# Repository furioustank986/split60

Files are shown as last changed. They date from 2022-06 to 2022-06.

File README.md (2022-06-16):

# split60
The Split60 is Huskeyboard's first full keyboard, meaning that it uses a unique case. The cases are designed to be able to combine and look like a normal 60% keyboard, although a cable will still need to connect the two halves. It is a sandwich mount case; linear switches are recommended.

The Split60 uses the traditional ANSI 60% layout, except that the spacebar is divided into 2.25u/1.25u/2.75u segments to allow the keyboard to be split.

Eight m3x0.5 * 10mm screws will be required for assembly.

The two halves are connected by a USB C-to-C cable using an i2c connection.

The keyboard uses the ATmega32u4 chip.

The keyboard does not come with any LEDs.

The typing angle is 7 degrees.

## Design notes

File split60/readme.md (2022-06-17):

# Split60

Split60

*A short description of the keyboard/project*

* Keyboard Maintainer: [huskeyboards](https://github.com/yourusername)
* Hardware Supported: *The PCBs, controllers supported*
* Hardware Availability: *Links to where you can find this hardware*

Make example for this keyboard (after setting up your build environment):

    make Split60:default

Flashing example for this keyboard:

    make Split60:default:flash

See the [build environment setup](https://docs.qmk.fm/#/getting_started_build_tools) and the [make instructions](https://docs.qmk.fm/#/getting_started_make_guide) for more information. Brand new to QMK? Start with our [Complete Newbs Guide](https://docs.qmk.fm/#/newbs).

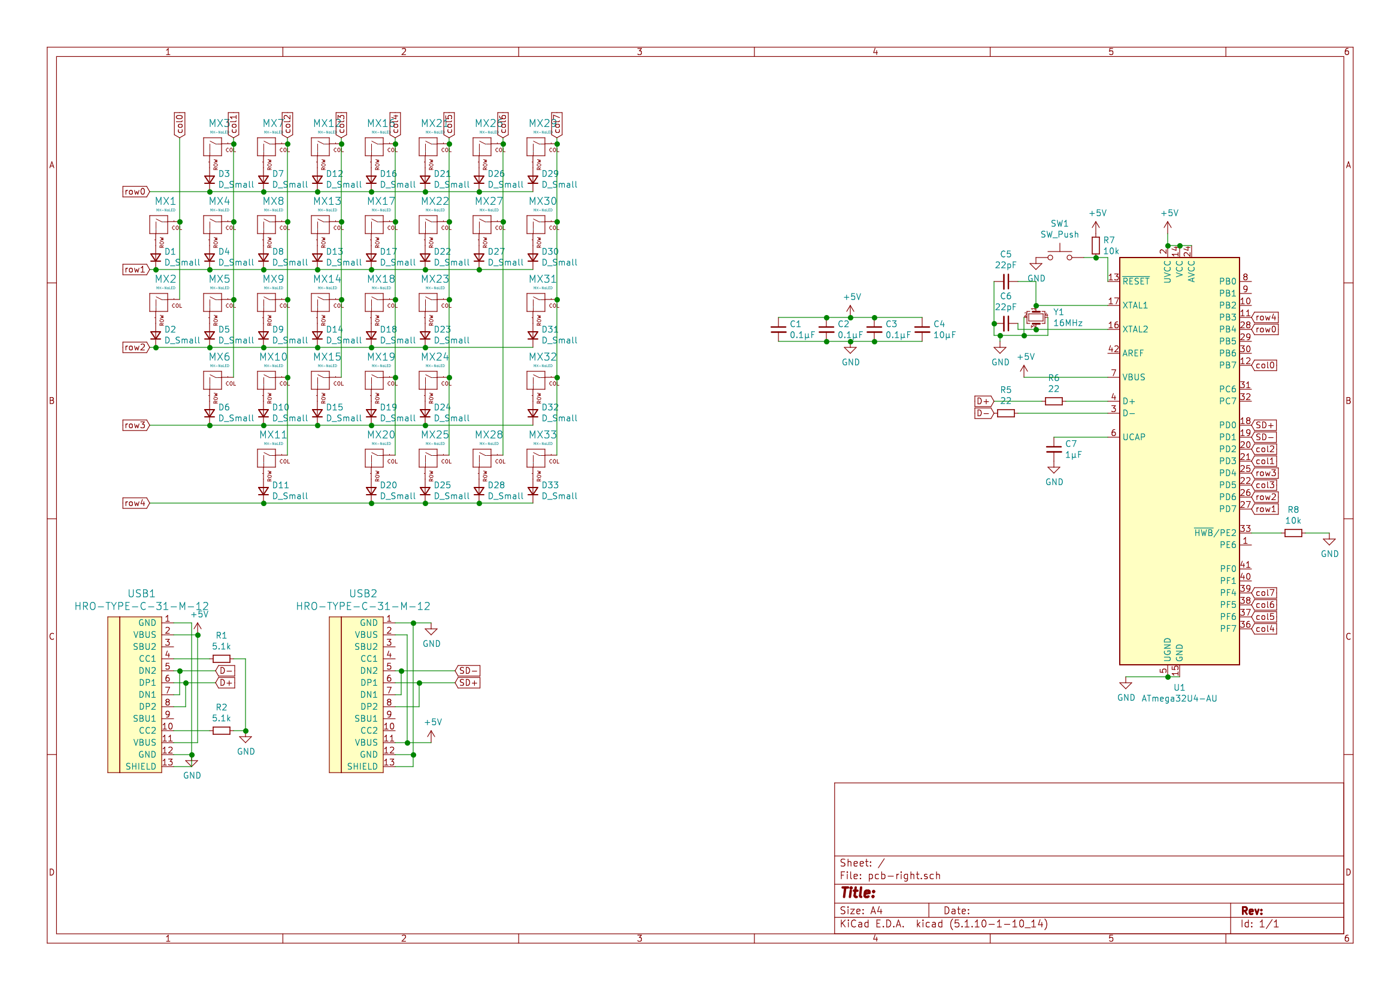
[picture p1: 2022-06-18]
pcb-right/Schematic_right.png

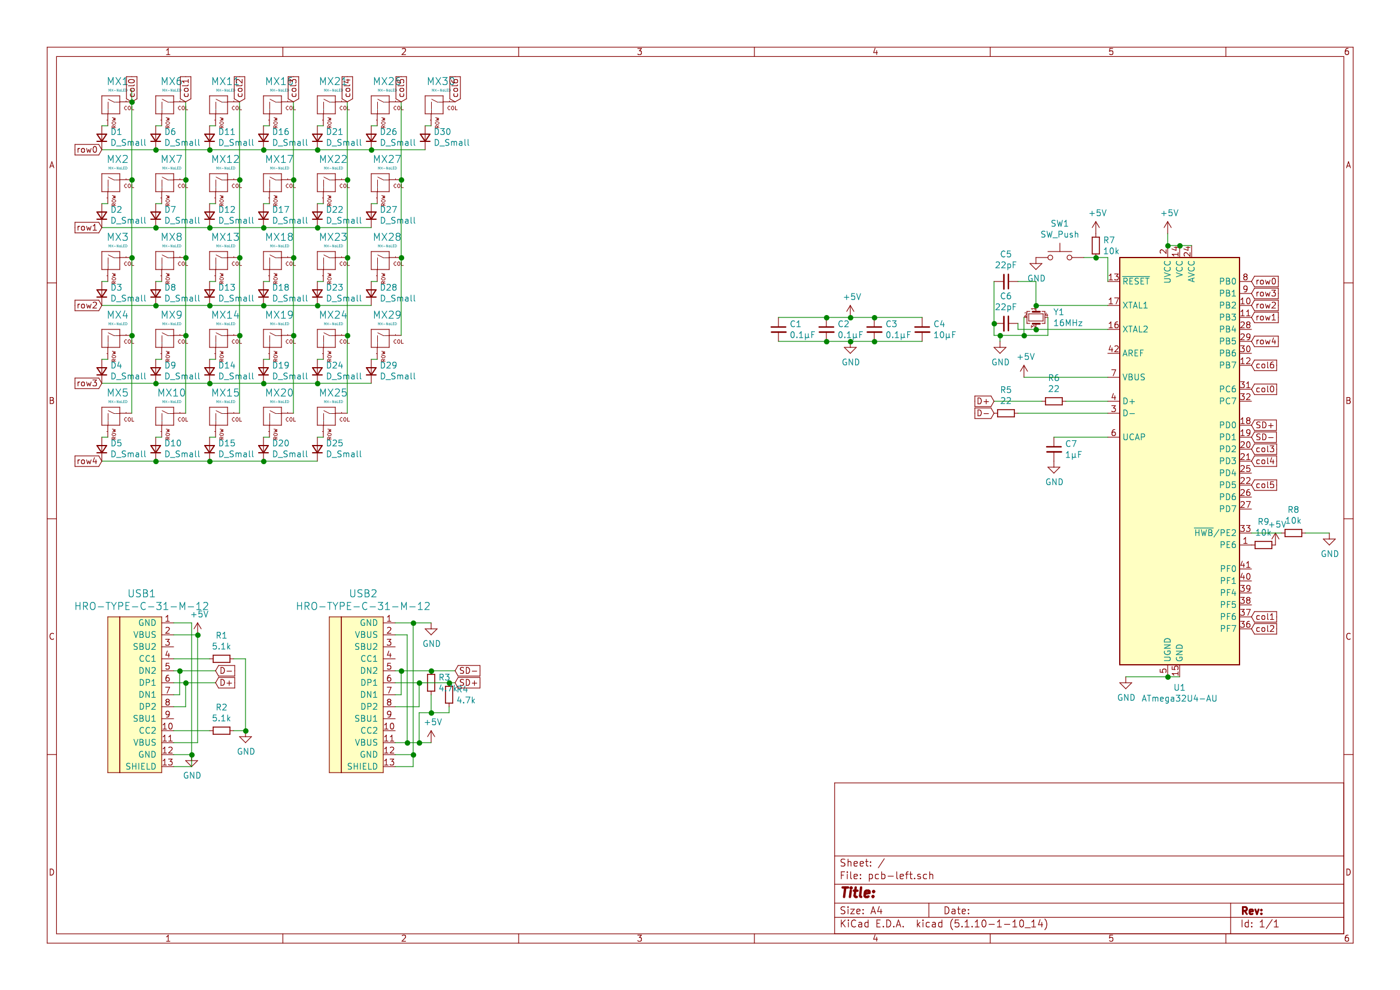
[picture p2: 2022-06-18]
pcb-left/Schematic_left.png

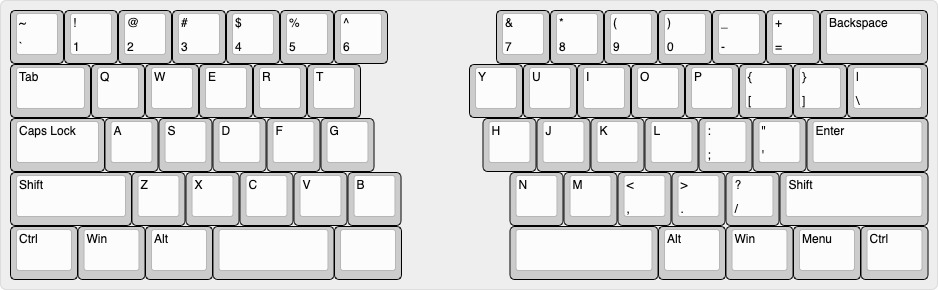
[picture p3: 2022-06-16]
keyboard-layout.jpg

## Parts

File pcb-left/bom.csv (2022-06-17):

Id | Designator | Package | Quantity | Designation | Supplier and ref
1 | MX19,MX28,MX27,MX30,MX21,MX29,MX26,MX24,MX23,MX22,MX18,MX17,MX16,MX14,MX13,MX12,MX11,MX9,MX8,MX7,MX6,MX1 | MXOnly-1U-NoLED | 22 | MX-NoLED
2 | R9,R8,R7 | R_0805_2012Metric | 3 | 10k
3 | MX20,MX4 | MXOnly-2.25U-NoLED | 2 | MX-NoLED
4 | MX15,MX25,MX10,MX5 | MXOnly-1.25U-NoLED | 4 | MX-NoLED
5 | Y1 | Crystal_SMD_3225-4Pin_3.2x2.5mm | 1 | 16MHz
6 | USB2,USB1 | HRO-TYPE-C-31-M-12-Assembly | 2 | HRO-TYPE-C-31-M-12
7 | U1 | TQFP-44_10x10mm_P0.8mm | 1 | ATmega32U4-AU
8 | SW1 | SKQG-1155865 | 1 | SW_Push
9 | R6,R5 | R_0805_2012Metric | 2 | 22
10 | R4,R3 | R_0805_2012Metric | 2 | 4.7k
11 | R2,R1 | R_0805_2012Metric | 2 | 5.1k
12 | MX3 | MXOnly-1.75U-NoLED | 1 | MX-NoLED
13 | MX2 | MXOnly-1.5U-NoLED | 1 | MX-NoLED
14 | D30,D29,D28,D27,D26,D25,D24,D23,D22,D21,D20,D19,D18,D17,D16,D15,D14,D13,D12,D11,D10,D9,D8,D7,D6,D5,D4,D3,D2,D1 | D_SOD-123 | 30 | D_Small
15 | C7 | C_0805_2012Metric | 1 | 1µF
16 | C6,C5 | C_0805_2012Metric | 2 | 22pF
17 | C4 | C_0805_2012Metric | 1 | 10µF
18 | C3,C2,C1 | C_0805_2012Metric | 3 | 0.1µF

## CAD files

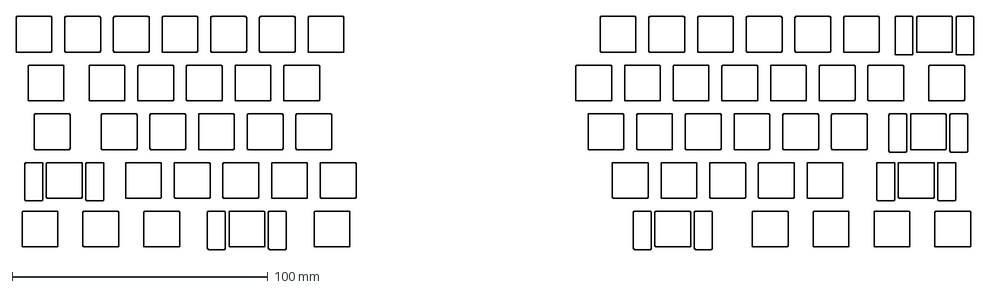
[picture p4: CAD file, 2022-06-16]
kbplate.dxf
374.9 x 91.2 mm

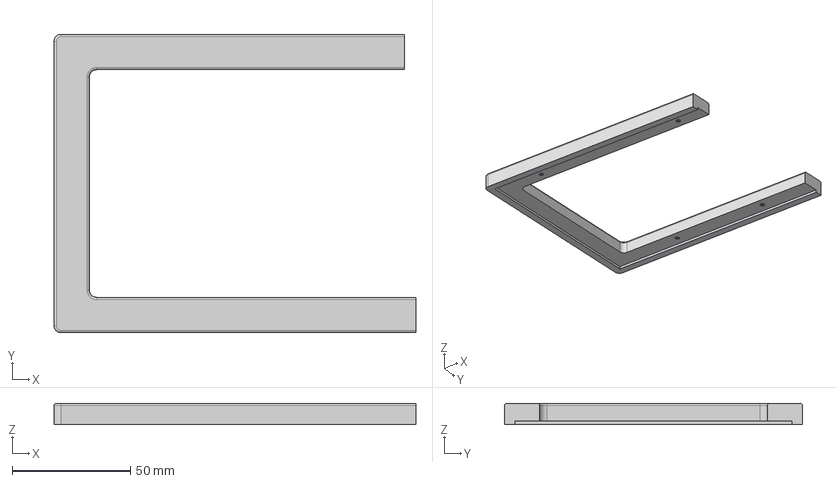
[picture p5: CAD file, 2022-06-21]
step files v2/Top-left.step
153.1 x 126.2 x 9.00 mm

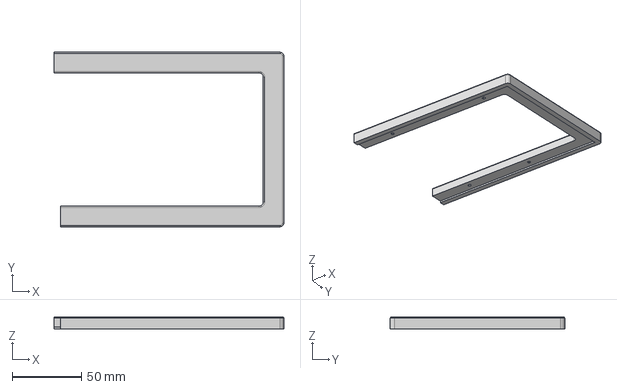
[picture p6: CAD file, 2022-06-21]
step files v2/Top-right.step
166.3 x 126.2 x 9.00 mm

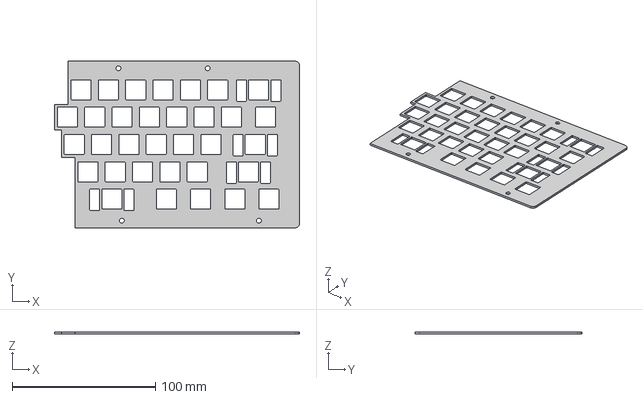
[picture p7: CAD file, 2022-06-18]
step files v2/Plate-right.step
170.8 x 116.2 x 1.50 mm

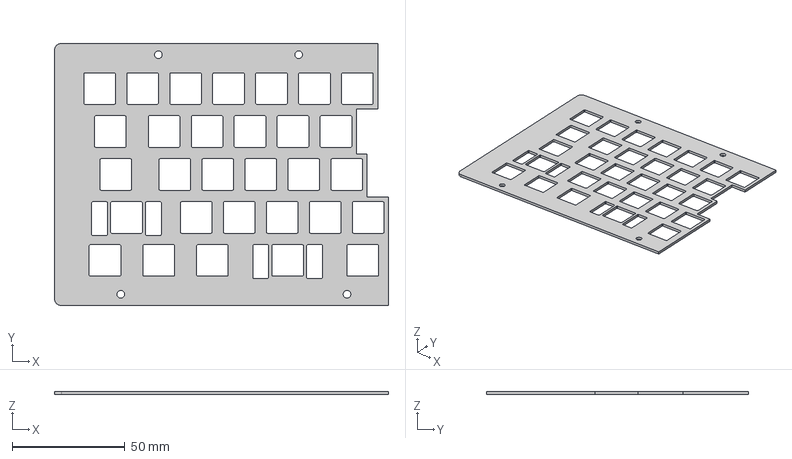
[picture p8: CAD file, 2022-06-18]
step files v2/Plate-left.step
148.1 x 116.2 x 1.50 mm

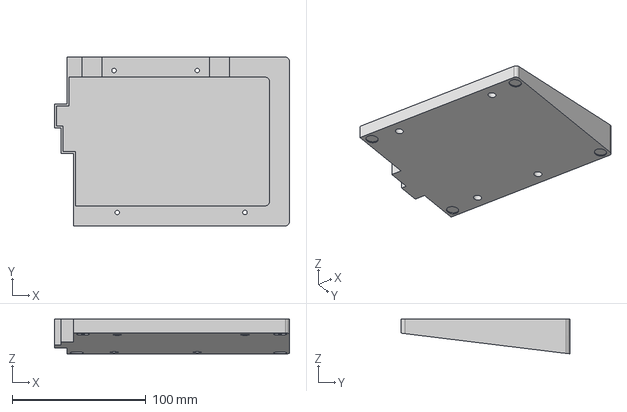
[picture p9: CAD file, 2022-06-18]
step files v2/Bottom-right.step
175.8 x 126.2 x 26.0 mm

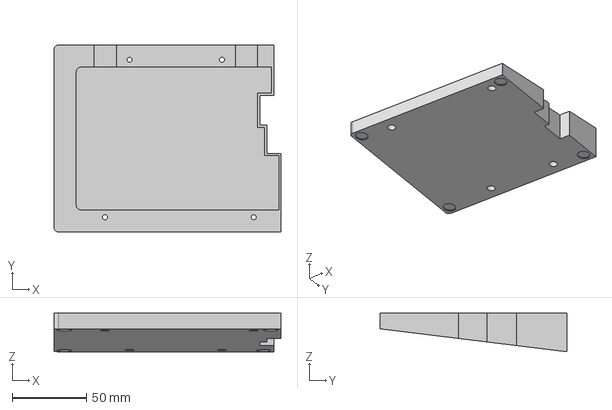
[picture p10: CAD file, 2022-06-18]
step files v2/Bottom-left.step
153.1 x 126.2 x 26.0 mm

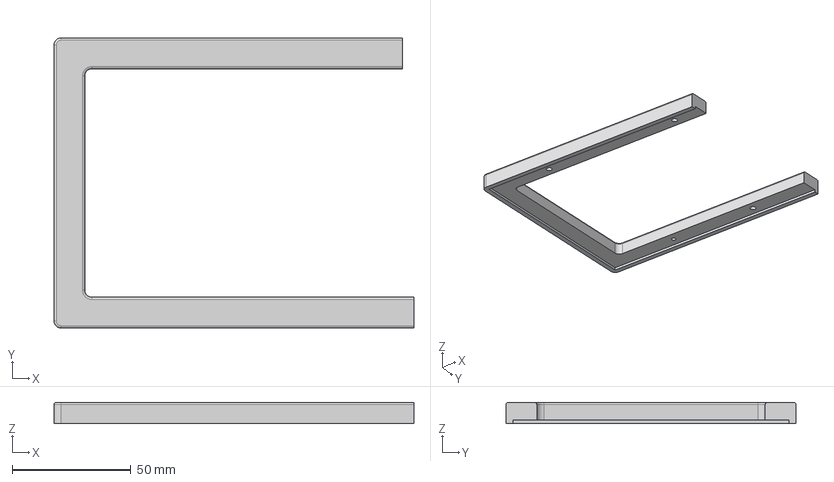
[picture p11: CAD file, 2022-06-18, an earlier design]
step files/split60_Top-left v1.step
151.6 x 122.2 x 9.00 mm

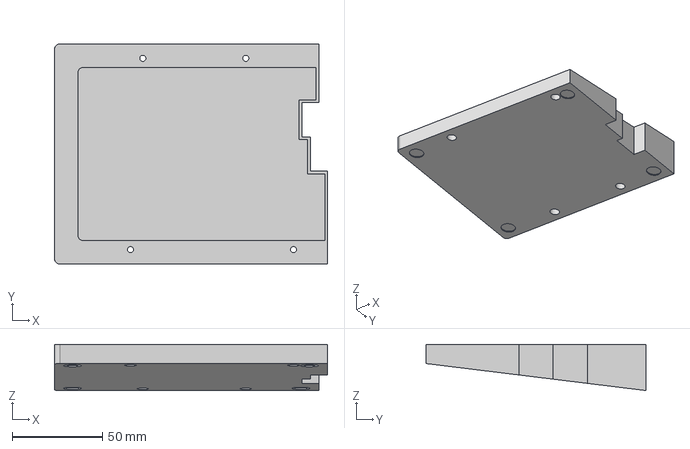
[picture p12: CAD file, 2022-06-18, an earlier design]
step files/split60_Bottom-left v1.step
151.6 x 122.2 x 25.6 mm

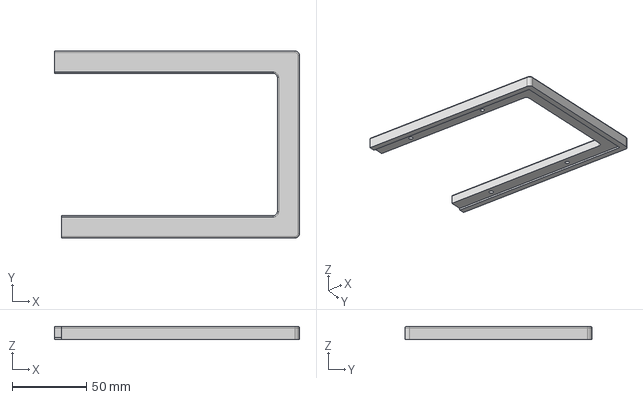
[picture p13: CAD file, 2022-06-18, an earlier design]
step files/split60_Top-right v1.step
165.5 x 126.2 x 9.00 mm

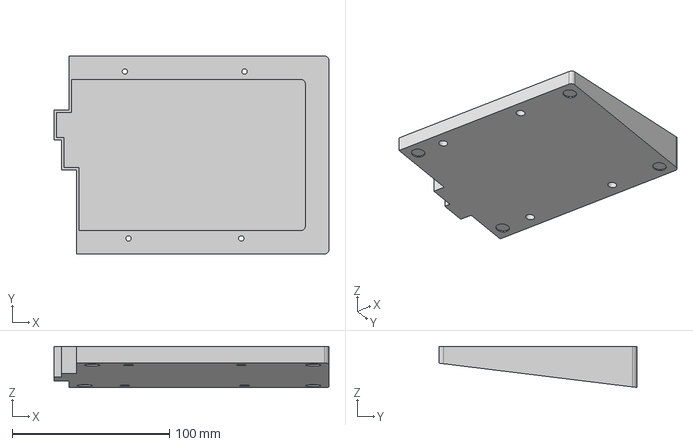
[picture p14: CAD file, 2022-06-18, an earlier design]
step files/split60_Bottom-right v1.step
175.0 x 126.2 x 26.1 mm

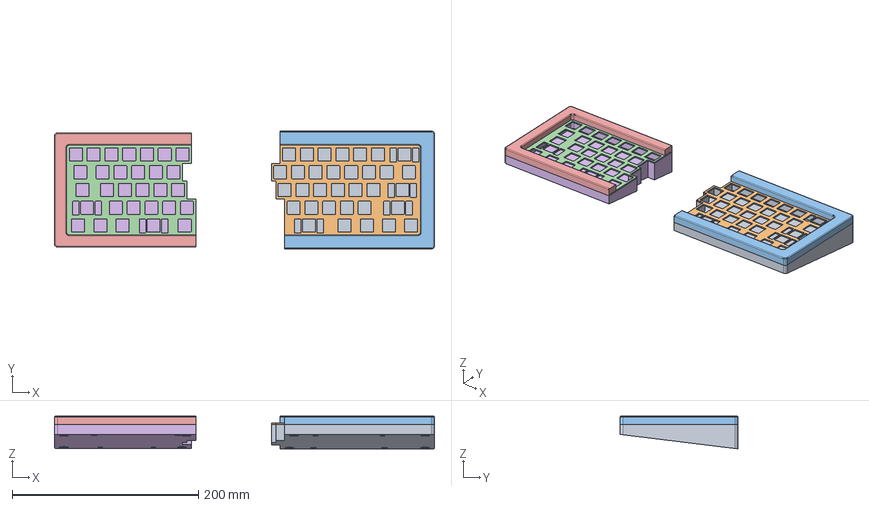
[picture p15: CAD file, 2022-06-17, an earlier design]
step files/Split60.step
407.6 x 126.2 x 35.1 mm
Bottom-right
Plate-right
Top-right
Plate-left
Top-left
Bottom-left

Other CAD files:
step files/split60_Plate-right v1.step
step files/split60_Plate-left v1.step
Split60 v2.2 _commodore_.f3d
split60 v1.f3d
split60 v2.1.f3d
split60 v2.f3d

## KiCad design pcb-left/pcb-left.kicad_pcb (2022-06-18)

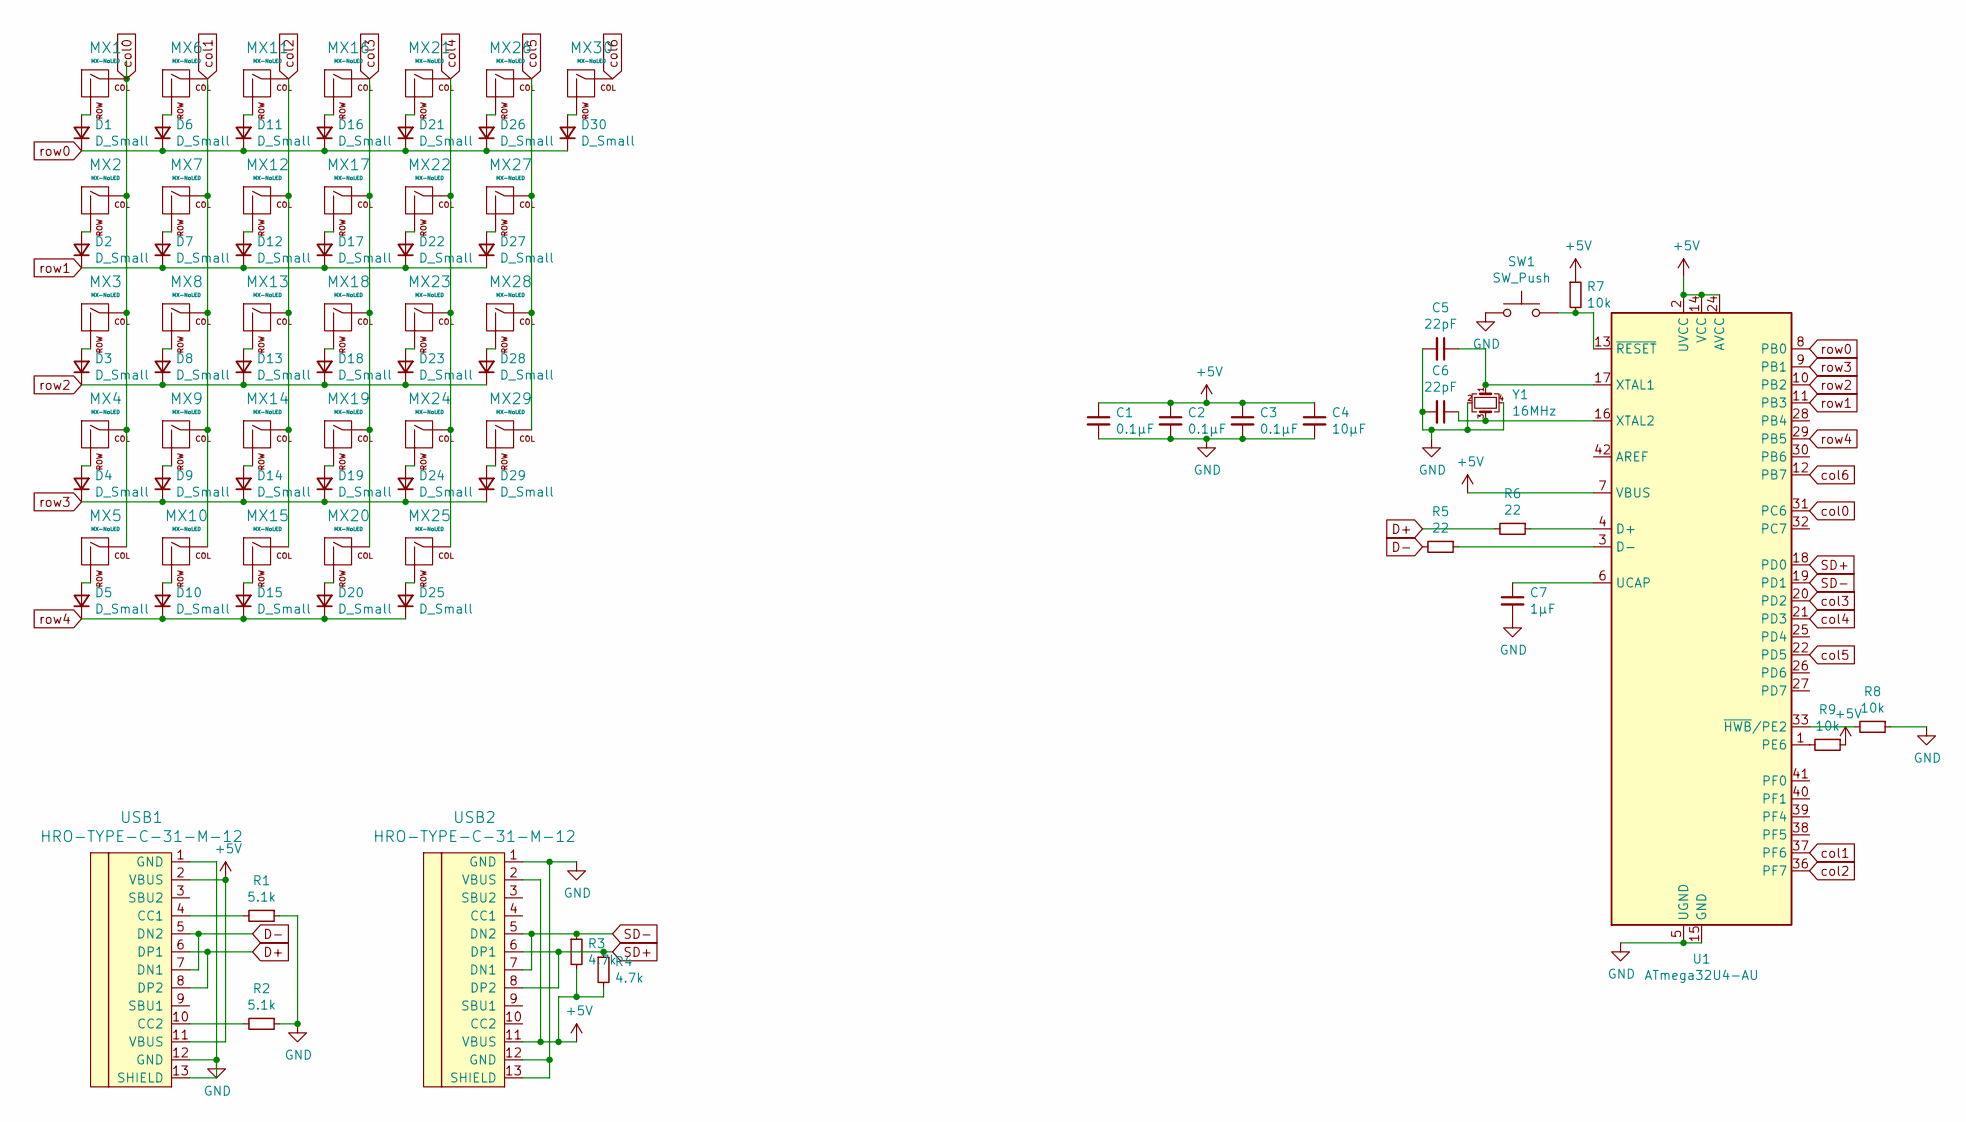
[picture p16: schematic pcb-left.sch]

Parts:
C1, C2, C3: 0.1µF; C_0805_2012Metric
C4: 10µF; C_0805_2012Metric
C5, C6: 22pF; C_0805_2012Metric
C7: 1µF; C_0805_2012Metric
D1, D2, D3, D4, D5, D6, D7, D8, D9, D10, D11, D12, D13, D14, D15, D16, D17, D18, D19, D20, D21, D22, D23, D24, D25, D26, D27, D28, D29, D30: D_Small; D_SOD-123
MX1, MX6, MX7, MX8, MX9, MX11, MX12, MX13, MX14, MX16, MX17, MX18, MX19, MX21, MX22, MX23, MX24, MX26, MX27, MX28, MX29, MX30: MX-NoLED; MXOnly-1U-NoLED
MX2: MX-NoLED; MXOnly-1.5U-NoLED
MX3: MX-NoLED; MXOnly-1.75U-NoLED
MX4, MX20: MX-NoLED; MXOnly-2.25U-NoLED
MX5, MX10, MX15, MX25: MX-NoLED; MXOnly-1.25U-NoLED
R1, R2: 5.1k; R_0805_2012Metric
R3, R4: 4.7k; R_0805_2012Metric
R5, R6: 22; R_0805_2012Metric
R7, R8, R9: 10k; R_0805_2012Metric
SW1: SW_Push; SKQG-1155865
U1: ATmega32U4-AU; TQFP-44_10x10mm_P0.8mm
USB1, USB2: HRO-TYPE-C-31-M-12; HRO-TYPE-C-31-M-12-Assembly
Y1: 16MHz; Crystal_SMD_3225-4Pin_3.2x2.5mm

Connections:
+5V: C1.1, C2.1, C3.1, C4.1, R3.2, R4.2, R7.1, R9.1, U1.2 (UVCC), U1.7 (VBUS), U1.14 (VCC), U1.24 (AVCC), U1.34 (VCC), U1.44 (AVCC), USB1.2 (VBUS), USB1.11 (VBUS), USB2.2 (VBUS), USB2.11 (VBUS)
D+: R6.2, USB1.6 (DP1), USB1.8 (DP2)
D-: R5.2, USB1.5 (DN2), USB1.7 (DN1)
GND: C1.2, C2.2, C3.2, C4.2, C5.2, C6.2, C7.2, R1.1, R2.1, R8.1, SW1.1, U1.5 (UGND), U1.15 (GND), U1.23 (GND), U1.35 (GND), U1.43 (GND), USB1.1 (GND), USB1.12 (GND), USB1.13 (SHIELD), USB2.1 (GND), USB2.12 (GND), USB2.13 (SHIELD), Y1.2, Y1.4
unnamed: C5.1, U1.17 (XTAL1), Y1.1
unnamed: C6.1, U1.16 (XTAL2), Y1.3
unnamed: C7.1, U1.6 (UCAP)
unnamed: D1.2 (A), MX1.2 (ROW)
unnamed: D2.2 (A), MX2.2 (ROW)
unnamed: D3.2 (A), MX3.2 (ROW)
unnamed: D4.2 (A), MX4.2 (ROW)
unnamed: D5.2 (A), MX5.2 (ROW)
unnamed: D6.2 (A), MX6.2 (ROW)
unnamed: D7.2 (A), MX7.2 (ROW)
unnamed: D8.2 (A), MX8.2 (ROW)
unnamed: D9.2 (A), MX9.2 (ROW)
unnamed: D10.2 (A), MX10.2 (ROW)
unnamed: D11.2 (A), MX11.2 (ROW)
unnamed: D12.2 (A), MX12.2 (ROW)
unnamed: D13.2 (A), MX13.2 (ROW)
unnamed: D14.2 (A), MX14.2 (ROW)
unnamed: D15.2 (A), MX15.2 (ROW)
unnamed: D16.2 (A), MX16.2 (ROW)
unnamed: D17.2 (A), MX17.2 (ROW)
unnamed: D18.2 (A), MX18.2 (ROW)
unnamed: D19.2 (A), MX19.2 (ROW)
unnamed: D20.2 (A), MX20.2 (ROW)
unnamed: D21.2 (A), MX21.2 (ROW)
unnamed: D22.2 (A), MX22.2 (ROW)
unnamed: D23.2 (A), MX23.2 (ROW)
unnamed: D24.2 (A), MX24.2 (ROW)
unnamed: D25.2 (A), MX25.2 (ROW)
unnamed: D26.2 (A), MX26.2 (ROW)
unnamed: D27.2 (A), MX27.2 (ROW)
unnamed: D28.2 (A), MX28.2 (ROW)
unnamed: D29.2 (A), MX29.2 (ROW)
unnamed: D30.2 (A), MX30.2 (ROW)
unnamed: R1.2, USB1.4 (CC1)
unnamed: R2.2, USB1.10 (CC2)
unnamed: R5.1, U1.3 (D-)
unnamed: R6.1, U1.4 (D+)
unnamed: R7.2, SW1.2, U1.13 (~RESET)
unnamed: R8.2, U1.33 (~HWB~/PE2)
unnamed: R9.2, U1.1 (PE6)
SD+: R4.1, U1.18 (PD0), USB2.6 (DP1), USB2.8 (DP2)
SD-: R3.1, U1.19 (PD1), USB2.5 (DN2), USB2.7 (DN1)
col0: MX1.1 (COL), MX2.1 (COL), MX3.1 (COL), MX4.1 (COL), MX5.1 (COL), U1.31 (PC6)
col1: MX6.1 (COL), MX7.1 (COL), MX8.1 (COL), MX9.1 (COL), MX10.1 (COL), U1.37 (PF6)
col2: MX11.1 (COL), MX12.1 (COL), MX13.1 (COL), MX14.1 (COL), MX15.1 (COL), U1.36 (PF7)
col3: MX16.1 (COL), MX17.1 (COL), MX18.1 (COL), MX19.1 (COL), MX20.1 (COL), U1.20 (PD2)
col4: MX21.1 (COL), MX22.1 (COL), MX23.1 (COL), MX24.1 (COL), MX25.1 (COL), U1.21 (PD3)
col5: MX26.1 (COL), MX27.1 (COL), MX28.1 (COL), MX29.1 (COL), U1.22 (PD5)
col6: MX30.1 (COL), U1.12 (PB7)
row0: D1.1 (K), D6.1 (K), D11.1 (K), D16.1 (K), D21.1 (K), D26.1 (K), D30.1 (K), U1.8 (PB0)
row1: D2.1 (K), D7.1 (K), D12.1 (K), D17.1 (K), D22.1 (K), D27.1 (K), U1.11 (PB3)
row2: D3.1 (K), D8.1 (K), D13.1 (K), D18.1 (K), D23.1 (K), D28.1 (K), U1.10 (PB2)
row3: D4.1 (K), D9.1 (K), D14.1 (K), D19.1 (K), D24.1 (K), D29.1 (K), U1.9 (PB1)
row4: D5.1 (K), D10.1 (K), D15.1 (K), D20.1 (K), D25.1 (K), U1.29 (PB5)

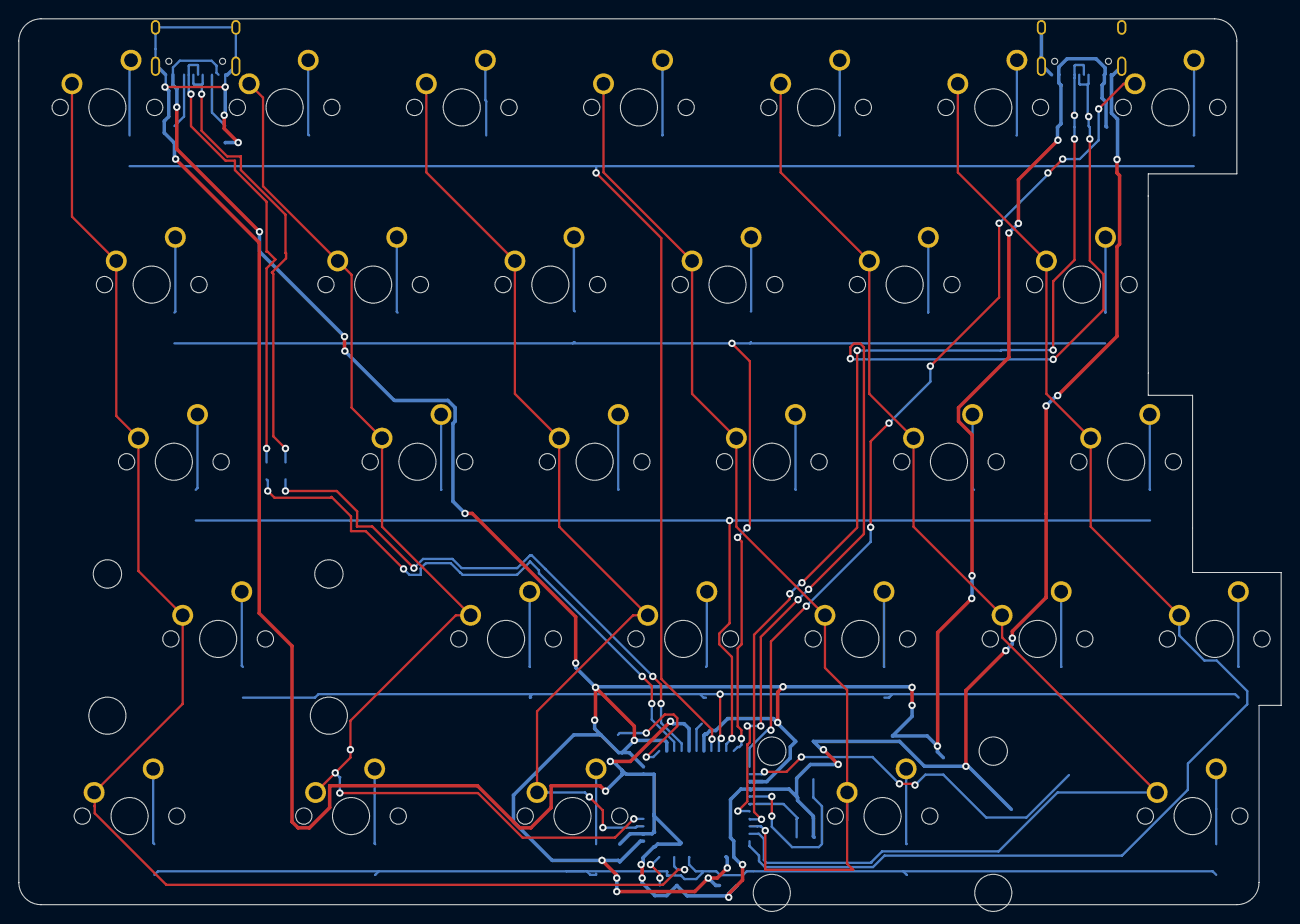
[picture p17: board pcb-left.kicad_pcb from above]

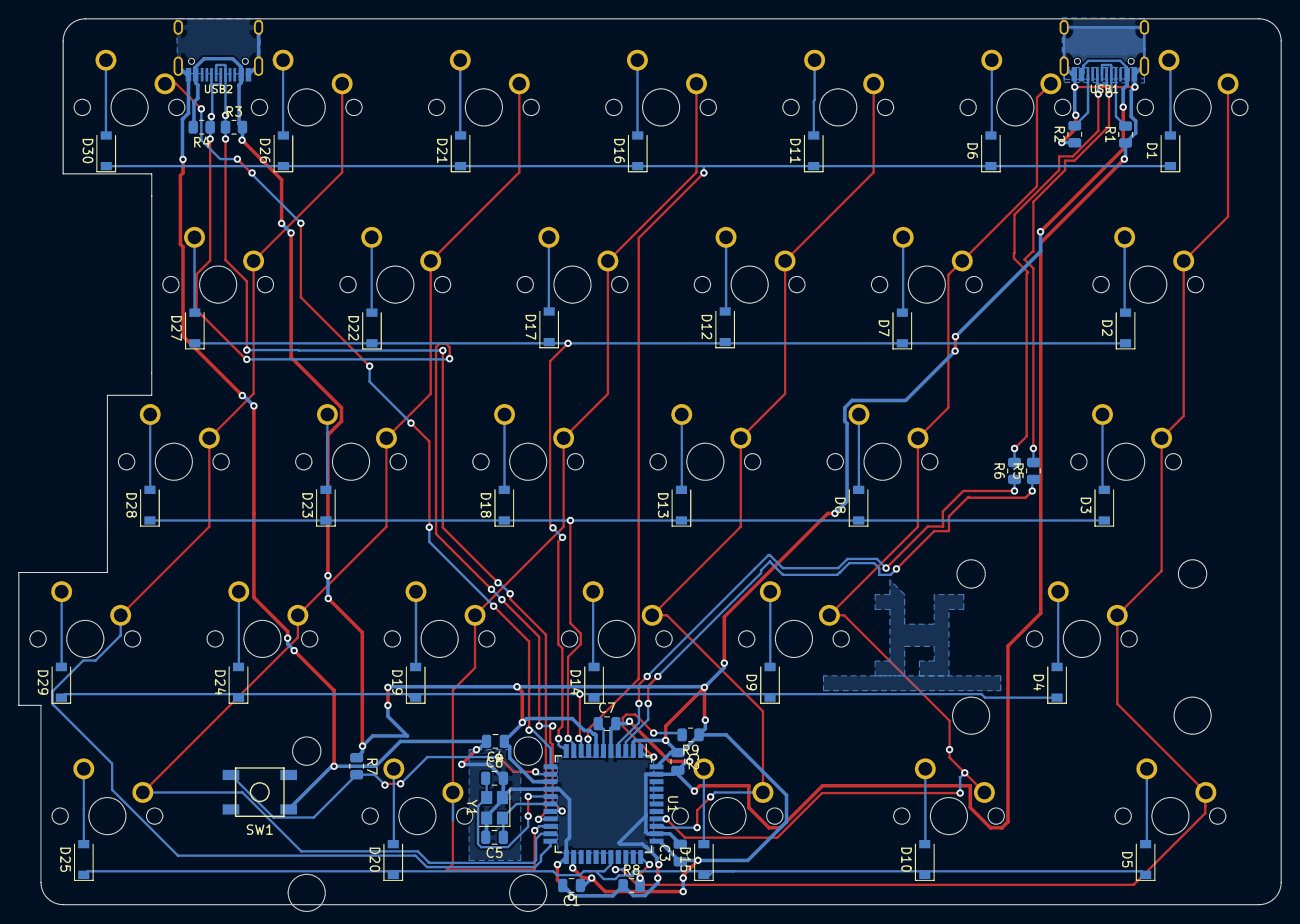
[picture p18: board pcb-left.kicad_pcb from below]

Board: 2 copper layers, 135.7 x 95.2 mm, 81 parts (51 on the bottom side), 58 nets.

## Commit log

2022-06-16 added base files for case and plate
    [kbplate.dxf, split60 v3.f3d]
2022-06-16 added case and screw holes. TODO: Connector holes
    [split60 v3.f3d]
2022-06-16 added schematic for left PCB
    [pcb-left.kicad_pcb, pcb-left.sch]
2022-06-16 Added proper screw holes and feet holes
    [split60 v3.f3d]
2022-06-16 added pcb files
    [pcb-left.sch]
2022-06-17 finished left side pcb
    [pcb-left.kicad_pcb, pcb-left.sch]
2022-06-17 finalized left side pcb
    [Split60.step, pcb-left.kicad_pcb, pcb-left.sch]
2022-06-17 added right side pcb
    [pcb-right.kicad_pcb, pcb-right.sch]
2022-06-17 added files for manufacturing right side pcb
    [BOM.csv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]
2022-06-17 added production files for left pcb
    [bom.csv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]
2022-06-18 re-zoned crystal area
    [pcb-left.kicad_pcb, pcb-right.kicad_pcb]
2022-06-18 added schematics as png for easy reference
2022-06-18 added step files
    [Split60.step, split60 v3.f3d, split60_Bottom-left v1.step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]
2022-06-18 added f3d
    [split60 v1.f3d]
2022-06-18 fixed crystal zone
    [pcb-left.kicad_pcb]
2022-06-18 added more case design concepts
    [split60 v2.1.f3d, split60 v2.f3d]
2022-06-18 added fillet
    [Bottom-left.step, Bottom-right.step, Plate-left.step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]
2022-06-21 added commodore 64
    [Split60 v2.2 _commodore_.f3d, Top-left.step, Top-right.step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]
